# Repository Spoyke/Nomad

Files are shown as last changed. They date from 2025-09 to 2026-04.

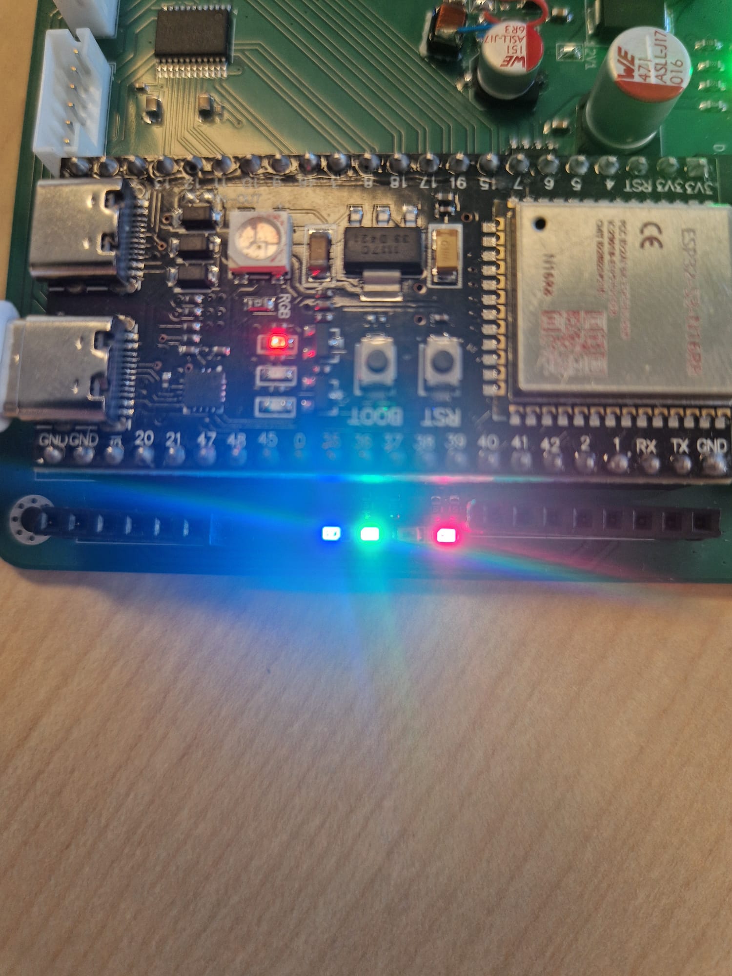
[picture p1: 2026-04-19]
Ressources/Fonctionnement de l'alimentation.jpeg

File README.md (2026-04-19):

 # **Son Spatial**
*Projet étudiant S7*

## Description du projet 

Ce projet a pour objectif de créer un système audio immersif mobile grâce à un réseau d’amplificateurs audio, capables de spatialiser le son. Le principe repose sur la distribution et le traitement différencié des signaux audio entre plusieurs amplificateurs, afin de recréer une expérience sonore 3D pour l’utilisateur. Le système s'adapte aux différentes pièces pour trouver 

### Principe de fonctionnement 

#### Microcontrôleur maître

- Reçoit le contenu audio à diffuser (ex : musique, film, jeu vidéo).
- Traite et décompose le signal audio pour chaque ampli, en fonction de leur position relative par rapport à l’utilisateur.
- Envoie les données audio adaptées à chaque ampli via un protocole de communication sans fil.

#### Amplificateurs audio

- Reçoivent les signaux audio spécifiques (ex du stéréo : piste gauche pour l’ampli gauche, piste droite pour l’ampli droit).
- Convertissent le signal numérique en signal analogique, l’amplifient, et le diffusent via des haut-parleurs.
- Synchronisent leur diffusion pour éviter les décalages.

### Exemple

Si un son provient de la gauche dans le contenu audio, l’utilisateur l’entendra principalement depuis l’ampli situé à sa gauche, avec une atténuation progressive vers la droite. Plus le nombre d’amplis est élevé (ex : 4 ou 6), plus la précision de la spatialisation est fine (avant/arrière, haut/bas).

## Architecture du projet

Le projet est divisé en deux parties principales, chacune avec des objectifs techniques spécifiques :

### Partie électronique

Cette partie correspond à la concéption et à la réalisation des amplificateurs audio.

#### Fonctions clés 

- Récupération du signal audio numérique
- Conversion numérique → analogique
- Amplification du signal

### Partie Informatique

Cette partie comporte la programmation des microcontroleurs (esp32), Rasberry PI, application mobile.
On vise à traiter le son et assurer une communication synchrone entre le microcontrôleur maître et les amplis.
- Le traitement de signal sera géré par la Rasberry Pi commandé via une interface mobile. 
- La communication entre l'application du telephone et la raspberry pi se fera via un serveur local WebSocket hebergé par la raspberry.
- La diffusion de la musique entre la raspberry pi et l'esp32 se fera à travers un serveur local Icecast hebergé par la raspberry.

### Partie mécanique

Cette partie vise à conceptionner plusieurs robots capables de se déplacer dans une pièce. 

#### Fonctions clés

- Extraction des pistes (gauche/droite, avant/arrière)
- Synchronisation des amplis

## Compte rendus de séance
### Séance 1 (16/09/2025)

*Julie, Simon, Gabriel* :

Réalisation en amont des schématique :
- Amplificateur audio pour diffuser du son via une application mobile
- Mécanique pour déplacer l'enceinte et éviter les obstacles
  
Mettre en commun les schématique afin de commander les composantes. 

*Axel, Aleksandar* : 

Etablir une communication entre les esp32 - Rasberry Pi - Téléphone
Transmission de son via une application mobile

### Séance 2 (23/09/2025)

"Julie, Simon, Gabriel" : 

- Fin de la réalisation et mise en commun des schémas de l'ampli audio et du robot.
- Ajout d'un capteur à ultrason au robot pour qu'il puisse détecter et anticiper les obstacles. Utilisation du HC-SR04.
- Choix final de l'esp32 et des empreintes des composants pour le PCB. 
- Début de la conception du PCB.

"Axel, Aleks" :

Design de l'interface de l'application
Début de communication entre un esp32 et la raspberry Pi

"Globale" :
- Recherche sur la façon dont les robots se localiser et comment l'implémenter : On utilisera l'intensité du signal émit par la raspberry pi à l'esp32 pour déterminer la distance entre les deux (plus l'intensité est faible, plus la distance est grande)

Planning prévisionnel :



### Séance 3 (30/09/2025)

Simon : commande des composants, continuer le PCB

Gabriel : Finition placement des composants pour le routage, routage des composants sauf pour l'esp32. 

Aleksandar : ecrire un code pour teste l'intensité d'un signal wifi avec un appareil. On remarque que des interférences viennent rapidement perturber le signal. Il faudrait amplifier le signal wifi ou trouver un autre solution pour le localisation des robots.

Axel : transmission d'un fichier audio avec la rasberry Pi sur l'esp32. Vérifier que le signal est bien lu sur l'esp32 avec un oscilloscope. Le son n'est pas assez puissant pour pouvoir l'écouter.Implémentation d'un système d'amplification du courant à la prochaine séance via le dac de l'esp32

Julie: conception mécanique du robot (modélisation Onshape)

### Séance 4 (07/10/2025)

Simon : Recherche sur les moyens de gérer les déplacement des amplis audio et reprérer les amplis dans l'espace. Utilisation de l'intensité du signal pour déterminer la distance entre la raspberry pi et les esp32. Et, les esp32 entre eux, en demendans au esp de transmettre un signal périodiquement pour permettre aux autres de déterminer la distance avec ce dernier. Dans le cas du projet de conférencier, le conférencier porte la raspberry pi et les esp32 se placent dans un rayon de 3m autour de ce dernier. Et, à une certaine distance (à déterminer) entre eux. Ainsi, chaque esp32 va essayer de rester à une distance de 3m du conférencier et suffisament espacé des autres esp32.

 Gabriel : Correction PCB

 Aleks : Correction du code pour l'intensité du signal wifi, manipulation entre deux ESP32 pour vérifier si l'un capte l'autre. On c'est procurer une antenne d'Arès que l'on a mis sur l'ESP32 ce qui a permis de corriger la perturbation des signaux et augmenter leur intensité à la réception de l'ESP32. Vérification de l'intensité du signal émis par un partage de connexion d'iphone en fonction de la distance

 Julie : Conception méca 

 Axel : Lecture du son reçue sur l'esp32 depuis la raspberry avec l'ampli audio LM386. Actuellement le son est de très mauvaise qualitée, mais reconnaisable, car il est diffusé par le DAC de l'esp32. Deux objectifs pour la prochaine séance : - essayer un autre DAC pour voir si la qualité est meilleurs et mise en place de l'application pour commencer le contrôle de la raspberry via le telephone.

### Séance 5 (21/10/2025)

Aleks : Implémentation d'un système de connexion dans le code qui scan les signaux Wi-Fi aux alentours, a présent, il est possible de se connecter a un réseau Wi-Fi tant que l'ESP32 capte le signal et tant que l'on connait le mot de passe du wifi (falcutatif)

Axel : Utilisation du LM386 mais peu fructueuse car il faut mettre un son de très faible amplitude ( ~= 50 mv max à cause du gain de 20 de l'ampli ), qui est presque impossible à avoir avec le DAC 8 bits de l'esp32. Test d'un ampli audio I2S pendant les vacances.

Simon : Début du travaille sur la synchronisation des ESP32 : La raspberry pi envoit des pacquets de données d'une taille à définir en fonction de la qualité du son et de la mémoire disponible sur l'esp32. Dans ce paquet, il y a 3 éléments : l'heure (nombre de microseconde depuis l'epoch) de la rasbperry pi lors de l'envoie du paquet, l'heure où le son doit être joué par l'esp32 et les données du son. De cette façon, la latence peut être estimer la latence qu'il y a eu en comparant l'heure de transmission et l'heure de l'esp32.  

Gabriel : finalisation pcb, creation gerbers, envoi en production

### Séance 6 (4/11/2025)

Aleks : Début de code sur la spatialisation des ESP32, le but sera d'estimer (pour l'instant de manière ni précise et plutôt naïve) la distance entre l'esp32 et la raspberry en fonction de l'intensité RSSI du signal wif.

Axel : Sur mon réseau wifi à domicile, tout est ok niveau transmission de l'audio et synchronisation. Arrivé à l'école, je me rends compte que le réseau de l'ecole bloque certains port d'écoute nécessaire à la partie informatique. Changement du partie du moyen de communication ( Mqtt -> serveur local WebSocket ).

Simon : Mise en place de multithreading pour permettre à l'esp32 de réaliser ses tâches (réception, émission, déplacement et envoit du son à l'ampli audio) en parallèle. Et, travaille sur la synchronisation : mise en place d'une queue pour stocker les paquets reçuent et pas encore traités car la réception des données est plus rapide que le traitement des paquets. Une fois le traitement du paquet terminé, le code créé un timer qui se déclanchera dans (heure du son à jouer - heure raspberry pi).  
 
Gabriel : verification avancement commande pcb, tests de fonctionnement capteur ultrasons, point sur la repartition des tâches avec le reste de l'equipe

Julie : Impression du premier prototypage du boîtier d'ampli audio. Tester l'ultrason et les moteurs pour la prochaine séance. Il faut aussi commander les moteurs, les esp32, les haut parleurs et les batteries pour la prochaine séance. 

### Séance 7 (19/11/2025)

Gabriel : Entretien sur fiche de compétances, recherche composants pour soudure pcb, reflexion à des solutions aux problèmes d'empruntes de composants 

Julie : Soudure des composants

Simon et Aleks : Travail sur la mesure de la distance entre les esp32 pour qu'ils puissent rester à une certaine distance les uns des autres. La première idée, d'utilisé le RSSI comme avec la raspberry pi ne fonctionne pas. La communication n'est pas direct, elle passe par la raspberry pi. Une solution serait d'utiliser ESP-Now pour communiquer directement entre les esp32 mais, cela signifierait de devori couper la communication wifi avec la raspberry pi quelque temps pour émettre un signal capté par les autres esp32.

Axel : Le son est synchronisé avec 3 esp32s, il faut maintenant le spatialiser.

### Séance 8 (25/11/2025)

Axel : Le son est maintenant stéréo. Prochaine étape : enregistrement et diffusion de la voix via un micro I2S

Simon Et Aleks : On a fait fonctionner le capteur à ultrason pour détecter les obstabcles sur la routes des amplis. Et, on a commencé travaillé sur le fonctionnement des moteurs.

Gabriel et Julie : Soudure des composants qui n'avaient pas les bonnes empruntes. Reflexion sur la prochaine version du pcb

### Séance 9 (02/12/2025)

Gabriel : Test du fonctionnement des composants et du fonctionnent général de la carte. applications solutions des problèmes de composants.

Simon : Test du PCB, la diode de schotky protégeant le circuit bloque la tension d'alimentation de 12V. Il y a des étincelles lorsqu'on branche le 12 d'une alim de labo à la carte. Le LDO ne fonctionne pas, il ne sort pas de 5V, le problème peut venir des soudures qui sont moins bonnes à cette endroit. Le LDO transformant le 5V en 3.3V fonctionne mais chauffe beaucoup, il n'y a peut être pas de problème, le drive moteur peut demander beaucoup de courant, ce qui fait chauffer le composant mais, il faudra réfléchir à un moyen de réduire la chaleur du composant dans le prochain PCB. Les Leds indiquant qu'il y a du 12V et du 1.8V ne fonctionnent pas (composant déféctueux ?). On a commencé à câbler la partie amplification avec l'esp32 mais il faut adapter le code pour pouvoir contrôler le composant.  

Axel : Test du micro I2S pas concluant => prochaine solutions : utilisation du micro du telephone

Aleks : Début de recherche et de programmation pour le mouvement des moteurs

Point sur la solution technique du déplacement et la répartition des tâches: 
Capture d’écran 2025-11-04 à 19 11 56

### Séance 10 (09/12/2025)

Axel : Test du micro I2S enfin concluant, possibilité de le lire sur le pc, il faut maintenant l'envoyer sur le serveur icecast

Gabriel : Répartition des composants sur 3 cartes differentes avec Simon, création projets kicad pour les prochains pcbs, schéma elec carte commande, recherche empruntes et symboles pour composants.

Simon : Travail sur le schéma du PCB de la partie audio, vérification des calculs, du choix et du placments des composants. Tout est bon, le plus gros changement par rapport à la version antérieur est le fait d'utiliser le PWR_MODE1 de l'ampli qui lorsque l'amplification est faible, l'ampli tire son alimentation depuis une source externe plus faible (qui vient du buck) pour moins consommer. Cependant, il faut vérifier que le courant fournit par le buck peut supporter cet ajout et s'il peut le faire sans problème (chauffe etc...). Réflexion sur le déplacment des robots, j'ai trouvé une façon qui même si elle est peu précise devrait suffire pour l'application, sans ajouter de nouveau composant : le robot cherche à se mettre à une certaine distance de la raspberry pi avec le calcul de distance basé sur le RSSI du signal reçu. Et, avec les deux capteurs à ultrasons, le robot cherche à se mettre à une certaine distance des autres robots (les capteurs à ultrasons ayant une porté de 4m). On peut donc faire en sorte que les robots soit à bonne distance de la raspberry pi et les uns des autres pour fournir un son sur une large zone, ce qui est le but du conférencier.  

Aleks : Continuation de la programmation du mouvement des moteurs, mesure et estimation de la distance entre l'esp32 et la raspberry PI avec le RSSI

### Séance 11 (16/12/2025)

Aleks : Estimation de la distance entre esp32 et Raspberry PI faite, code du MotorDriver (TB6612FNG) terminé (en théorie). Objectif de la prochaine séance : codé un encodeur et les moteurs en eux-même.

Simon : Réalisation du PCB de la partie audio qui est presque terminé, mais il faudra attendre la prochaine séance pour envoyer la commande et être sûr qu'il puisse être utilisé avec les autres modules du robot (connecteurs aux bons endroits et dont la connexion entre les autres PCB n'est pas géné par les composants. J'ai aussi fait un bilan du courant consommé par le robot et je me suis rendu compte que le buck ne pourrait pas fournir un courant suffisant lorsque tous les composants fonctionnent au maximum (ce qui devrait être assez rare). On a donc décidé avec Gabriel d'utiliser deux buck (soit le buck actuelle qui sera utilisé jusqu'à ce qu'on le remplace par un autre buck plus puissant à un endroit prévu. Soit on utilise deux fois le même buck mais un des deux serait décdié au fonctionnement de l'ampli.).  

### Séance 12 (13/01/2026)

Tout le monde : Mise en accord sur le planning prévisionnel

Aleks : début de la partie cartographie en expérimentant des capteurs dont le fonctionnement est similaire à un Lidar à l'aide d'une librairie Arduino, pour le moment pas de résultat concret à cause de certaine erreur lié a la partie programmation et au branchement des PINs

Simon : Mise au propre du planning prévisionnel sur Google Agenda (lien tout en bas). Fin du routage de la partie audio.

Gabriel : Finitions schéma elec carte CMD, début routage carte CMD, verification routage partie audio

Axel : Début d'utilisation et de diffusion du son du micro sur un esp32.

Julie : Revoir les capteurs pour mesurer la distance de capture objet
Modifier et finir la schématique pour l'implémenter avec le PCB d'alimentation. Voir avec Gabriel pour le routage. 

### Séance 13 (20/01/2026)

Simon : Fin du routage du PCB de la partie audio. 

Gabriel : Routage PCB Cmd, recherche composants.

Axel : Complication au niveau de la diffusion de la voix, un problème surement lié au format de données envoyée

Julie: Etude des capteurs

Aleks : Fonctionnement du détecteur infrarouge VL53L0X, estimation correcte jusqu'a une distance d'environ 1m.

### Séance 14 (27/01/2026)

Gabriel : fin du routage pcb cmd

Simon : Fin du routage de la partie audio (adaptation du pcb de la partie audio au pcb de la partie commande). J'ai aussi essayé de faire fonctionner le premier PCB (en enlevant le buck qui ne fonctionnait pas) pour faire des tests avec l'ampli audio. Notamment communiquer avec lui et le configurer pour qu'il soit conforme à ce qu'on à besoin (puissance maximale, moyen de communication (I2S), type d'alimentation...). 

Axel : La transmission du micro depuis le telephone vers l'esp32 est fonctionnelle

Julie : Branchement d'un moteur avec le module driver pour faire tourner le moteur. 

Aleks: Finalisation "théorique" du programme concernant la cartographie, mais il faut tester ce dernier.

### Séance 15 (03/02/2026)

Julie : Deuxième prototype de boitier imprimé 3D. A tester avec deux moteurs et mesurer le courant nominal pour un fonctionnement normal. Voir le support le poids avec l'assemblage. 

Simon et Aleks : On a essayé de faire fonctionner l'ampli de l'ancien PCB. Le PCB a différents problème comme le manque de résistance de pull-up sur les pins de l'I2C. Ce qui a compliquer la tâche. Au final, on arrive à envoyer la configuration à l'ampli mais on n'arrive pas à demander des données de l'ampli. 

Gabriel : finalisation du routage cmd + création d'un schéma de cablage pour le test des moteurs. Cablage de ces moteurs et début de création d'un programme de test.

### Séance 16 (10/02/2026)

Simon et Aleks : On a compris pourquoi la communication avec le TAS2780 ne fonctionnait pas : l'ampli utilise du 1.8V pour ses pins numériques alors que l'esp32 utilise du 3.3V. Et en recevant du 3.3V, l'ampli se met en sécurité. Ce qui empêche la communication. 

Gabriel : Continuation du programme de test moteurs, réussite, les moteurs tournent. Tests avec Julie du couple des moteurs alimentés directement sans controleur sur le prototype du robot, et tests de couple sur les moteurs controlés depuis l'esp 32.

Axel : Avancement dans la voix, plus beaucoup de micro coupures dues au rechargement du buffer

Julie : Reprise du PCB Commande, notamment il faut changer les empreintes suite à l'arrivée de la deuxième version du PCB contenant des mauvaise empreintes. 

### Séance 17 (17/02/2026)

Simon et Gabriel : Soudure de la carte 

Julie : Continuation du PCB commande. La commander pour la recevoir à la rentrée. 

### Séance 18 (10/03/2026)

Simon : Soudure des derniers composants sur le pcb audio (connecteur). Et test de la carte : -> la communication I2C fonctionne mais pour l'instant il n'y a pas de son en sortie de l'ampli. 

Gabriel : Création montage pour test encodeurs et début création code test encodeurs.

Julie : Continuation du PCB commande

### Séance 19 (17/03/2026)

Gabriel : Test encodeurs, création morceaux de code pour detecter le sens de rotation du moteur aunsi que valeur absolue pour vérifier vitesse. Finitions pcb fait par Julie.

Julie : Verification PCB et commande du PCB.

Simon : Travail sur le PCB de la partie audio -> L'I2C semble fonctionner

### Séance 20 (24/03/2026)

Gabriel : Finitions code encodeurs, test avec driver moteurs.

Julie : Soudure sur le PCB commandé la semaine précédente. Vérification des erreurs corrigés (empreintes, tailles pistes pour laisser passer le courant). Dimension du boitiers à refaire pour optimiser l'emplacement du PCB, moteurs et haut parleur. 

Simon : Travail sur le PCB de la partie audio, l'I2C semble fonctionner mais je ne sais pas pourquoi. Quand je met l'adresse du composant, la communication ne passe pas mais quand je met une autre adresse (0x38) la communication semble fonctionner sauf quand j'essaye de lire les valeurs d'un registre qui crée des problème. De même quand j'essai de lancer l'ampli, la communication ne fonctionne pas mais quand je n'essai pas de lancer l'ampli et que j'écrit seulement dans les registres de configuration, la communication semble fonctionner. Le problème vient peut être du pin d'adressage du composant mais après l'avoir ressoudé avec Patricia, je n'ai pas vu de différence dans les résultats. L'erreur dans la lecture vient peut-être du code qui ne terminait jamais la transmission mais encore, sans terminer la communication, j'avais des valeurs quand je lisais plusieurs registres différents et dans la même communication.

Axel : Son du micro enfin fonctionnel sur l'ESP32, il faut maintenant harmoniser le code de la gestion de l'audio

### Séance extra 21 (07/04/2026)

Teste de l'alimentation du PCB : 3V3, 5V, 12V marchent très bien. En revanche, le PCB audio fait court-circuiter une piste, ce qui entraine le surchauffe de la bobine. L'esp 32 est fonctionne bien sur le PCB et les connecteurs sont bien reliés aux capteurs. 

## Ressources

### Lien utiles

Diapo : https://docs.google.com/presentation/d/1eaNsvsmn-reTe-8X8-2-HZ8j_HwDIsKxUu0F8LIjo8Q/edit?usp=sharing \
Rapport : https://docs.google.com/document/d/1yTh4eJWGzI2o9GAGtWadODZ8SpGP1pLww7qxfcwqxjY/edit?usp=sharing \
https://www.notion.so/Partie-informatique-266923f17b6e80f486edd3fc771489f0 \
Infos MPU6050 https://docs.google.com/document/d/1O3AgjvM2_tZX7ABNkbS3lNtyRqeFLNvJ6qVK9URJxNs/edit?usp=sharing

### RSE

### Planning prévisionnel du 2nd semestre

https://calendar.google.com/calendar/ical/73473c3522efe55f20496e4b81c19aa0aaffa0a2a7005d1d658da9e635591a50%40group.calendar.google.com/public/basic.ics

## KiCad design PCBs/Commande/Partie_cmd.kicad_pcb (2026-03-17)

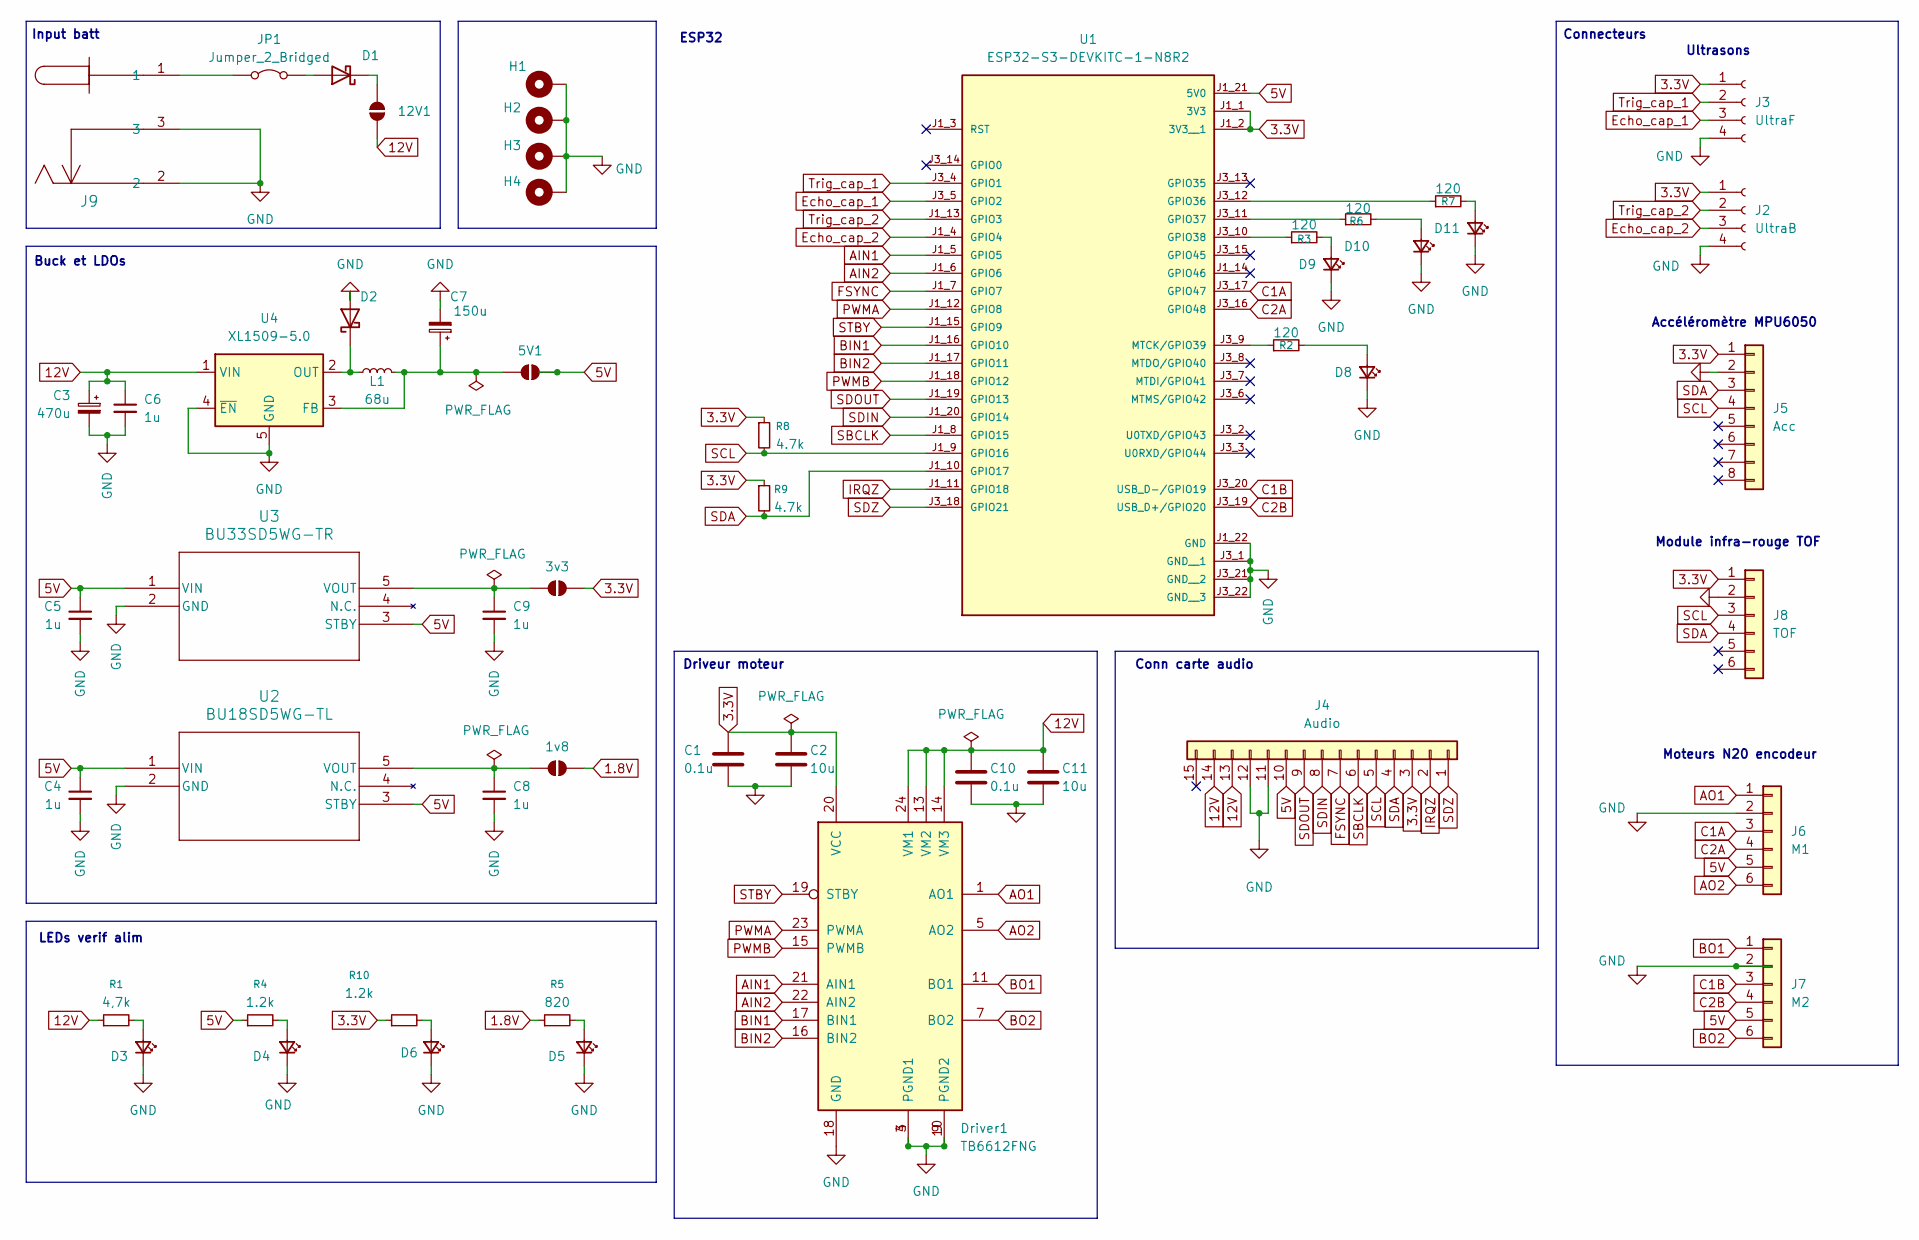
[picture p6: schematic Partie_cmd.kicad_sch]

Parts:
1v8, 3v3, 5V1, 12V1: SolderJumper_2_Open; SolderJumper-2_P1.3mm_Open_TrianglePad1.0x1.5mm
C1, C10: 0.1u; C_0402_1005Metric
C2, C11: 10u; C_0805_2012Metric
C3: 470u; CP_Elec_8x10.5
C4, C5, C6, C8, C9: 1u; C_0603_1608Metric_Pad1.08x0.95mm_HandSolder
C7: 150u; CP_Elec_6.3x7.7
D1, D2: MBRS320; D_SMC
D3, D4, D5, D6, D8, D9, D10, D11: LED_Small; LED_0603_1608Metric_Pad1.05x0.95mm_HandSolder
Driver1: TB6612FNG; SSOP-24_5.3x8.2mm_P0.65mm
H1, H2, H3, H4: MountingHole_Pad; MountingHole_2.5mm_Pad_Via
J2: UltraB; PinHeader_1x04_P2.54mm_Vertical
J3: UltraF; PinHeader_1x04_P2.54mm_Vertical
J4: Audio; PinSocket_1x15_P2.00mm_Vertical
J5: Acc; PinHeader_1x08_P2.54mm_Vertical
J6: M1; JST_PH_B6B-PH-K_1x06_P2.00mm_Vertical
J7: M2; JST_PH_B6B-PH-K_1x06_P2.00mm_Vertical
J8: TOF; PinHeader_1x06_P2.54mm_Vertical
J9: 694106105102; CONN3_06105102_WRE
JP1: Jumper_2_Bridged; TestPoint_2Pads_Pitch2.54mm_Drill0.8mm
L1: 68u; L_0805_2012Metric_Pad1.05x1.20mm_HandSolder
R1: 4,7k; R_0603_1608Metric_Pad0.98x0.95mm_HandSolder
R2, R3, R6, R7: 120; R_0603_1608Metric_Pad0.98x0.95mm_HandSolder
R4, R10: 1.2k; R_0603_1608Metric_Pad0.98x0.95mm_HandSolder
R5: 820; R_0603_1608Metric_Pad0.98x0.95mm_HandSolder
R8, R9: 4.7k; R_0603_1608Metric_Pad0.98x0.95mm_HandSolder
U1: ESP32-S3-DEVKITC-1-N8R2; XCVR_ESP32-S3-DEVKITC-1-N8R2; PARTREV V1
U2: BU18SD5WG-TL; SSOP5_ROM-L
U3: BU33SD5WG-TR; SSOP5_ROM-L
U4: XL1509-5.0; SOIC-8_3.9x4.9mm_P1.27mm

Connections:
1.8V: 1v8.2 (B), R5.1
3.3V: 3v3.2 (B), C1.1, C2.1, Driver1.20 (VCC), J2.1, J3.1, J4.3, J5.1, J8.1, R8.1, R9.1, R10.1, U1.J1_1 (3V3), U1.J1_2 (3V3__1)
5V: 5V1.2 (B), C4.1, C5.1, J4.10, J6.5, J7.5, R4.1, U1.J1_21 (5V0), U2.1 (VIN), U2.3 (STBY), U3.1 (VIN), U3.3 (STBY)
12V: 12V1.2 (B), C3.1, C6.1, C10.1, C11.1, Driver1.13 (VM2), Driver1.14 (VM3), Driver1.24 (VM1), J4.13, J4.14, R1.1, U4.1 (VIN)
AIN1: Driver1.21 (AIN1), U1.J1_5 (GPIO5)
AIN2: Driver1.22 (AIN2), U1.J1_6 (GPIO6)
AO1: Driver1.1 (AO1), Driver1.2 (AO1), J6.1
AO2: Driver1.5 (AO2), Driver1.6 (AO2), J6.6
BIN1: Driver1.17 (BIN1), U1.J1_16 (GPIO10)
BIN2: Driver1.16 (BIN2), U1.J1_17 (GPIO11)
BO1: Driver1.11 (BO1), Driver1.12 (BO1), J7.1
BO2: Driver1.7 (BO2), Driver1.8 (BO2), J7.6
C1A: J6.3, U1.J3_17 (GPIO47)
C1B: J7.3, U1.J3_20 (USB_D-/GPIO19)
C2A: J6.4, U1.J3_16 (GPIO48)
C2B: J7.4, U1.J3_19 (USB_D+/GPIO20)
Echo_cap_1: J3.3, U1.J3_5 (GPIO2)
Echo_cap_2: J2.3, U1.J1_4 (GPIO4)
FSYNC: J4.7, U1.J1_7 (GPIO7)
GND: C1.2, C2.2, C3.2, C4.2, C5.2, C6.2, C7.2, C8.2, C9.2, C10.2, C11.2, D2.2 (A), D3.1 (K), D4.1 (K), D5.1 (K), D6.1 (K), D8.1 (K), D9.1 (K), D10.1 (K), D11.1 (K), Driver1.3 (PGND1), Driver1.4 (PGND1), Driver1.9 (PGND2), Driver1.10 (PGND2), Driver1.18 (GND), H1.1, H2.1, H3.1, H4.1, J2.4, J3.4, J4.11, J4.12, J5.2, J6.2, J7.2, J8.2, J9.2, J9.3, U1.J1_22 (GND), U1.J3_1 (GND__1), U1.J3_21 (GND__2), U1.J3_22 (GND__3), U2.2 (GND), U3.2 (GND), U4.4 (~EN), U4.5 (GND), U4.6 (GND), U4.7 (GND), U4.8 (GND)
IRQZ: J4.2, U1.J1_11 (GPIO18)
unnamed: 1v8.1 (A), C8.1, U2.5 (VOUT)
unnamed: 3v3.1 (A), C9.1, U3.5 (VOUT)
unnamed: 5V1.1 (A), C7.1, L1.2, U4.3 (FB)
unnamed: 12V1.1 (A), D1.1 (K)
unnamed: D1.2 (A), JP1.2 (B)
unnamed: D2.1 (K), L1.1, U4.2 (OUT)
unnamed: D3.2 (A), R1.2
unnamed: D4.2 (A), R4.2
unnamed: D5.2 (A), R5.2
unnamed: D6.2 (A), R10.2
unnamed: D8.2 (A), R2.2
unnamed: D9.2 (A), R3.2
unnamed: D10.2 (A), R6.2
unnamed: D11.2 (A), R7.2
unnamed: J9.1, JP1.1 (A)
unnamed: R7.1, U1.J3_12 (GPIO36)
unnamed: R6.1, U1.J3_11 (GPIO37)
unnamed: R3.1, U1.J3_10 (GPIO38)
unnamed: R2.1, U1.J3_9 (MTCK/GPIO39)
PWMA: Driver1.23 (PWMA), U1.J1_12 (GPIO8)
PWMB: Driver1.15 (PWMB), U1.J1_18 (GPIO12)
SBCLK: J4.6, U1.J1_8 (GPIO15)
SCL: J4.5, J5.4, J8.3, R8.2, U1.J1_9 (GPIO16)
SDA: J4.4, J5.3, J8.4, R9.2, U1.J1_10 (GPIO17)
SDIN: J4.8, U1.J1_20 (GPIO14)
SDOUT: J4.9, U1.J1_19 (GPIO13)
SDZ: J4.1, U1.J3_18 (GPIO21)
STBY: Driver1.19 (STBY), U1.J1_15 (GPIO9)
Trig_cap_1: J3.2, U1.J3_4 (GPIO1)
Trig_cap_2: J2.2, U1.J1_13 (GPIO3)

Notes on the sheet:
Buck et LDOs
LEDs verif alim
Input batt
Accéléromètre MPU6050
Moteurs N20 encodeur
Module infra-rouge TOF
Ultrasons
ESP32
Connecteurs
Conn carte audio
Driveur moteur

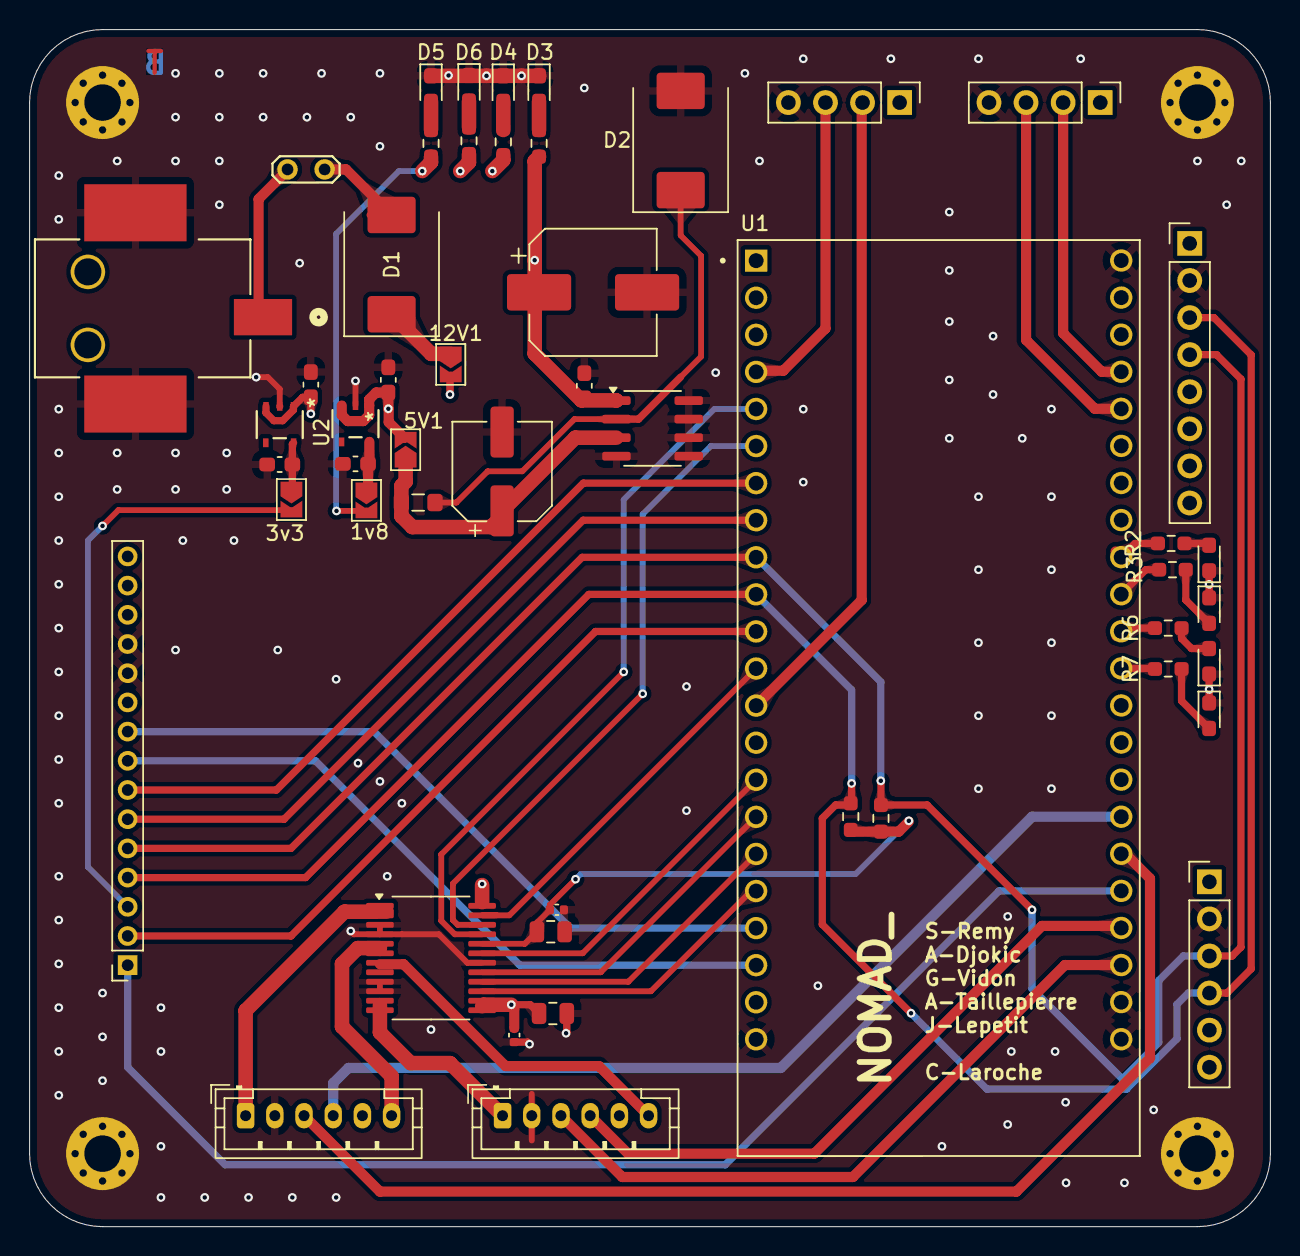
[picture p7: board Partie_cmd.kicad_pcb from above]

Board: 4 copper layers, 85.0 x 82.0 mm, 54 parts (0 on the bottom side), 51 nets.

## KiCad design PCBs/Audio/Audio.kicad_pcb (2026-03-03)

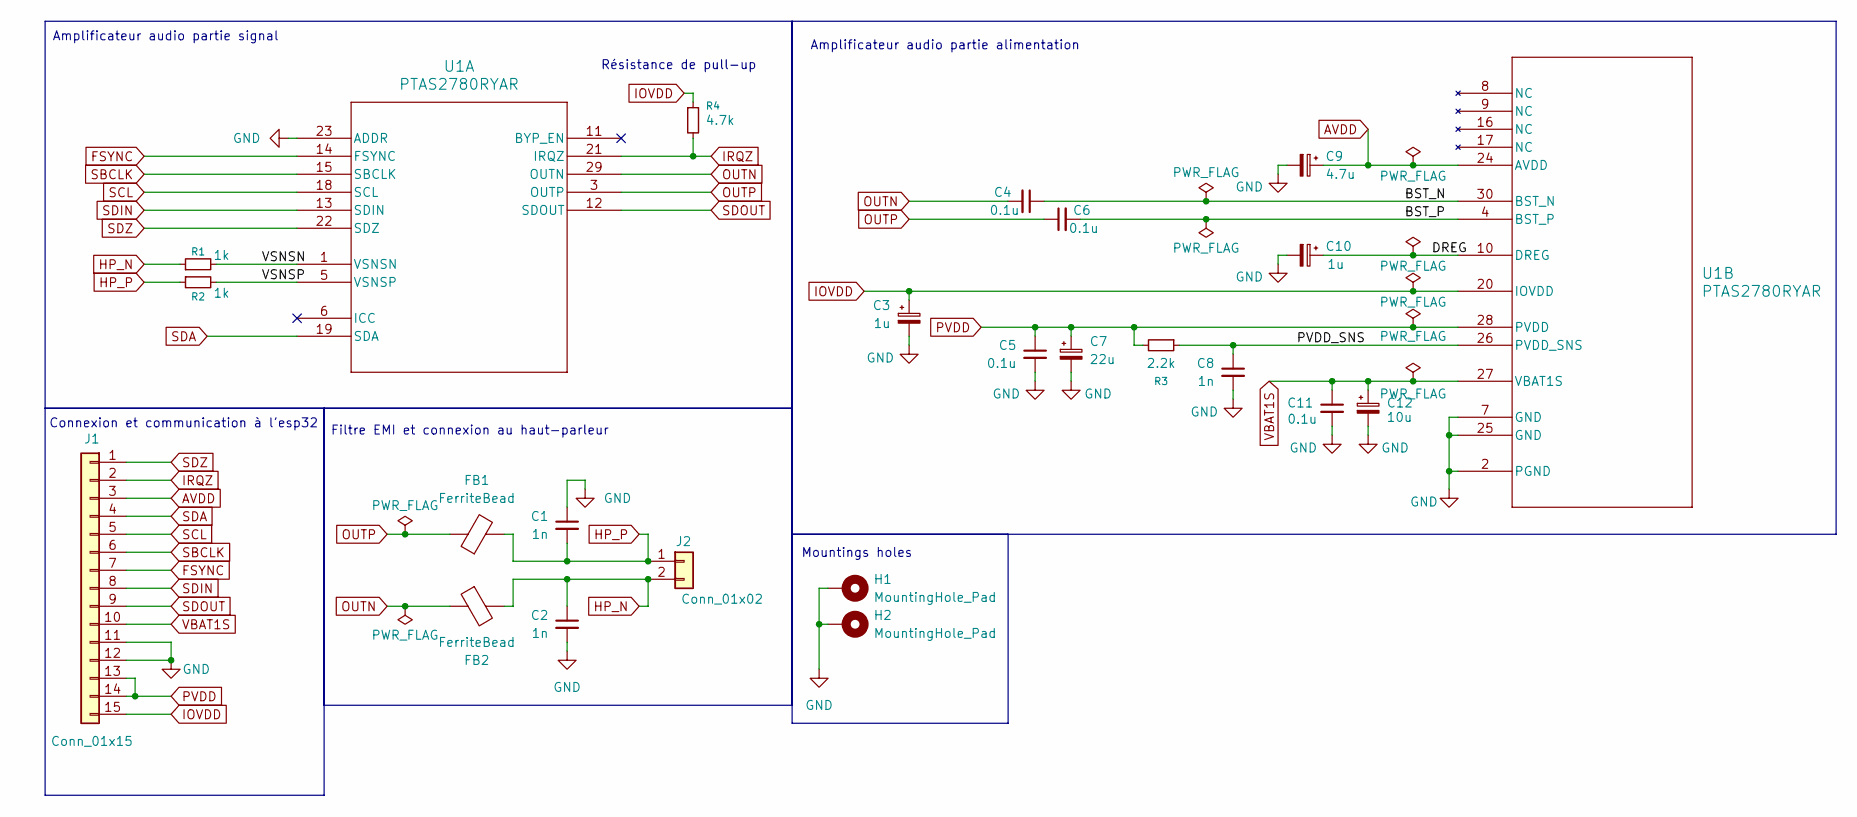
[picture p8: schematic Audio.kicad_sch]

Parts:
C1, C2, C8: 1n; C_0603_1608Metric_Pad1.08x0.95mm_HandSolder
C3, C10: 1u; C_0603_1608Metric_Pad1.08x0.95mm_HandSolder
C4, C6, C11: 0.1u; C_0603_1608Metric_Pad1.08x0.95mm_HandSolder
C5: 0.1u; C_0805_2012Metric_Pad1.18x1.45mm_HandSolder
C7: 22u; C_1210_3225Metric_Pad1.33x2.70mm_HandSolder
C9: 4.7u; C_0603_1608Metric_Pad1.08x0.95mm_HandSolder
C12: 10u; C_0805_2012Metric_Pad1.18x1.45mm_HandSolder
FB1, FB2: FerriteBead; C_1206_3216Metric_Pad1.33x1.80mm_HandSolder
H1, H2: MountingHole_Pad; MountingHole_2.2mm_M2_DIN965_Pad
J1: Conn_01x15; PinHeader_1x15_P2.00mm_Vertical
J2: Conn_01x02; PinHeader_1x02_P2.00mm_Vertical
R1, R2: 1k; R_0603_1608Metric_Pad0.98x0.95mm_HandSolder
R3: 2.2k; R_0603_1608Metric_Pad0.98x0.95mm_HandSolder
R4: 4.7k; R_0603_1608Metric_Pad0.98x0.95mm_HandSolder
U1: PTAS2780RYAR; VQFN-HR_RYA_TEX

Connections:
/BST_N: C4.1, U1.30 (BST_N)
/BST_P: C6.2, U1.4 (BST_P)
/DREG: C10.1, U1.10 (DREG)
/PVDD_SNS: C8.1, R3.1, U1.26 (PVDD_SNS)
/VSNSN: R1.2, U1.1 (VSNSN)
/VSNSP: R2.2, U1.5 (VSNSP)
AVDD: C9.1, J1.3, U1.24 (AVDD)
FSYNC: J1.7, U1.14 (FSYNC)
GND: C1.1, C2.2, C3.2, C5.2, C7.2, C8.2, C9.2, C10.2, C11.2, C12.2, H1.1, H2.1, J1.11, J1.12, U1.2 (PGND), U1.7 (GND), U1.23 (ADDR), U1.25 (GND)
HP_N: C2.1, FB2.2, J2.2, R1.1
HP_P: C1.2, FB1.2, J2.1, R2.1
IOVDD: C3.1, J1.15, R4.1, U1.20 (IOVDD)
IRQZ: J1.2, R4.2, U1.21 (IRQZ)
OUTN: C4.2, FB2.1, U1.29 (OUTN)
OUTP: C6.1, FB1.1, U1.3 (OUTP)
PVDD: C5.1, C7.1, J1.13, J1.14, R3.2, U1.28 (PVDD)
SBCLK: J1.6, U1.15 (SBCLK)
SCL: J1.5, U1.18 (SCL)
SDA: J1.4, U1.19 (SDA)
SDIN: J1.8, U1.13 (SDIN)
SDOUT: J1.9, U1.12 (SDOUT)
SDZ: J1.1, U1.22 (SDZ)
VBAT1S: C11.1, C12.1, J1.10, U1.27 (VBAT1S)

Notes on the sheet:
Amplificateur audio partie alimentation
Connexion et communication à l'esp32
Résistance de pull-up
Mountings holes
Amplificateur audio partie signal
Filtre EMI et connexion au haut-parleur

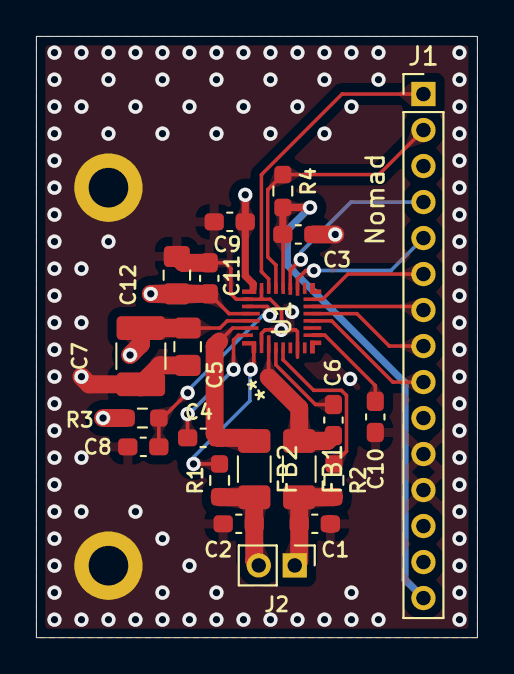
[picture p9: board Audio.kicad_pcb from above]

Board: 4 copper layers, 24.5 x 33.4 mm, 23 parts (0 on the bottom side), 23 nets.

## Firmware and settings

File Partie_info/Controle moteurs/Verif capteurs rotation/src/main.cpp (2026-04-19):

#include <Arduino.h>
#include <Wire.h>
#include <esp32-hal-ledc.h>

// put function declarations here:
int AI1 = 5; // GPIO pin for AI1 (pin 5)
int AI2 = 6; // GPIO pin for AI2 (pin 6)
int pwmPin = 8; // GPIO pin for PWM (pin 12)
int pwmChannel = 0;  // LEDC channel (0-15)
int pwmFreq = 20000; // Frequency in Hz
int pwmResolution = 8; // Resolution in bits (0-255 for 8 bit res)
int pinC1 = 47; // GPIO pin for encoder channel 1
int pinC2 = 48; // GPIO pin for encoder channel 2
int prevState = 0;
int encoderPosition = 0; // Position of the encoder

int ledpins[] = {39, 38, 37, 36}; // GPIO pins for LEDs (pins 39, 38, 37, 36)

// Quadrature transition table: index = (prevState << 2) | state
// +1 = clockwise, -1 = counterclockwise, 0 = no move/invalid
const int8_t transitionTable[16] = {
  0,  -1,  1,   0,
  1,   0,   0,  -1,
  -1,  0,   0,   1,
  0,   1,  -1,   0
};

void setup() {
  Serial.begin(115200);
  pinMode(AI1, OUTPUT);
  pinMode(AI2, OUTPUT);
  pinMode(pinC1, INPUT_PULLUP);
  pinMode(pinC2, INPUT_PULLUP);

  pinMode(ledpins[0], OUTPUT);
  pinMode(ledpins[1], OUTPUT);
  pinMode(ledpins[2], OUTPUT);
  pinMode(ledpins[3], OUTPUT);
  digitalWrite(ledpins[0], HIGH);
  digitalWrite(ledpins[1], HIGH);
  digitalWrite(ledpins[2], HIGH);
  digitalWrite(ledpins[3], HIGH);

  ledcSetup(pwmChannel, pwmFreq, pwmResolution); // channel, freq, resolution
  ledcAttachPin(pwmPin, pwmChannel); // attach GPIO pin to LEDC channel

  

  digitalWrite(AI1, LOW);
  digitalWrite(AI2, HIGH); // Setting to spin in one direction

  prevState = (digitalRead(pinC1) << 1) | digitalRead(pinC2);
  Serial.println("Setup finished.");
}

void loop() {
  int c1 = digitalRead(pinC1);
  int c2 = digitalRead(pinC2);
  int state = (c1 << 1) | c2;

  ledcWrite(pwmChannel, 100);

  if (state != prevState) {
    int index = (prevState << 2) | state;
    int8_t delta = transitionTable[index];
    if (delta == 1) {
      encoderPosition++;
      //Serial.println("Encoder turned clockwise");
    } else if (delta == -1) {
      encoderPosition--;
      //Serial.println("Encoder turned counterclockwise");
    }
    prevState = state;
  }

  static unsigned long lastPrint = 0;
  if (millis() - lastPrint >= 200) {
    lastPrint = millis();
    Serial.printf("Encoder pos: %d, AI1: %d, AI2: %d\n", encoderPosition, digitalRead(AI1), digitalRead(AI2));
    Serial.printf("PWM duty: %d\n", ledcRead(pwmChannel));
  }

}

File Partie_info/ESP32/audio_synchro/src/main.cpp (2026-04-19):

#include <Arduino.h>
#include <WiFi.h>
#include <WiFiUdp.h>
#include <WebSocketsClient.h>
#include "MyWebSocket.h"
#include "AudioLogger.h"
#include "SnapClient.h"
#include <WebSocketsClient.h>
#include <Audio.h>

// --- VARIABLES DE SYNCHRO ---
uint32_t targetEpochMillis = 0;
bool hasTargetTime = false;
const char url[] = "http://10.42.0.1:8000/streamleft";
// Pins pour gérer l'I2S
int _bck = 17, _ws = 18, _data = 16;    
int volume = 3;
const char *ssid = "MonHotspot";
const char *password = "axel1234";
bool isIcecast = true;
I2SStream out; 
WiFiClient wifi;
CopyDecoder decoder; 
SnapClient client(wifi, out, decoder);
Audio audio;
bool i2sInitialized = false; // Flag pour savoir si on doit désinstaller
void releaseI2S() {
    Serial.println("Libération des ressources I2S...");
    
    // On n'arrête que si cela a déjà été lancé
    if (i2sInitialized) {
        // On arrête les flux logiciels d'abord
        audio.stopSong(); 
        out.end();
        
        // On désinstalle le driver hardware proprement
        i2s_driver_uninstall((i2s_port_t)0); 
        i2sInitialized = false;
        delay(100); // Petite pause pour laisser le hardware respirer
    }
}

void init_I2S_SnapCast(){ 
  releaseI2S();
  
  auto cfg = out.defaultConfig(TX_MODE);
  cfg.pin_bck = _bck;
  cfg.pin_ws = _ws;
  cfg.pin_data = _data;
  cfg.sample_rate = 44100;
  cfg.channels = 2;
  cfg.bits_per_sample = 16;
  client.setVolumeFactor(.25);
  
  out.begin(cfg);
  client.begin();
  
  i2sInitialized = true; // On marque comme initialisé
  isIcecast = false;
}

void init_I2S_Icecast(){
  releaseI2S();
  
  audio.setPinout(_bck, _ws, _data);
  audio.setVolume(volume);
  
  i2sInitialized = true; // On marque comme initialisé
  isIcecast = true;
}

void webSocketEvent(WStype_t type, uint8_t * payload, size_t length) {
    switch(type) {
        case WStype_TEXT: {
            char target[8], command[16], content[32];
            if (!extractField((char*)payload, "target", target, sizeof(target))) return;            
            if (strcmp(target, "esp32") == 0) {
                extractField((char*)payload, "command", command, sizeof(command));
                extractField((char*)payload, "content", content, sizeof(content));

                if (strcmp(command, "Sync") == 0) {   
                  //  init_I2S_Icecast();                 
                    init_I2S_Icecast();
                    targetEpochMillis = atoll(content);
                    hasTargetTime = true;
                } else if (strcmp(command, "Stop") == 0) {
                    if(audio.isRunning()){
                        audio.stopSong();
                        Serial.println("Lecture arrêtée.");
                    }
                    init_I2S_SnapCast();
                } else if (strcmp(command, "Volume") == 0) {
                    volume = atoi(content);
                    audio.setVolume(volume);
                }
            }
        } break;
        case WStype_DISCONNECTED: Serial.println("WS Déconnecté"); break;
        case WStype_CONNECTED: Serial.println("WS Connecté"); break;
        default: break;
    }
}

void setup() {
  Serial.begin(115200);
  WiFi.begin(ssid, password);
  while (WiFi.status() != WL_CONNECTED) {
    delay(500);
    Serial.print(".");
  }
  Serial.println("Connecté !");
  
  WS_init(webSocketEvent); 
}

void loop() {
  WS_loop();  
  if(isIcecast){
    audio.loop();
    if (hasTargetTime) {
      audio.setVolume(volume);
      audio.connecttohost(url);
      hasTargetTime = false;
    }
  }
  else{
    client.doLoop();
  }

  
}

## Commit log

2025-09-23 Nouvelle version schéma kicad
    changement de nom + nouveau schéma elec
    [Nomad.kicad_pcb, Nomad.kicad_sch]
2025-09-23 retouches schema elec
    [Nomad.kicad_sch]
2025-09-25 Merged branches
    [ESP32-DEVKITC-32UE.step, Nomad.kicad_pcb, Nomad.kicad_sch]
2025-09-26 small fixes
    resolved erc errors
    [Nomad.kicad_sch]
2025-09-30 routage pcb
    finitions placement composants + routage
    [Nomad.kicad_pcb, Nomad.kicad_sch]
2025-09-30 Fin routage
    Fin routage sauf pour esp
    [Nomad.kicad_pcb]
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2025-10-06 Finished routing and silkscreen placement
    todo Gerber
    [Nomad.kicad_pcb, Nomad.kicad_sch]
2025-10-07 schéma ancien routage final ver
    [Nomad.kicad_pcb]
2025-10-07 encore plus de routage :(
    Todo, rapprocher au max capa de découplage
    grossir pistes alim au max
    [Nomad.kicad_pcb]
2025-10-08 Fin routage
    pls j'espère que c'est fini
    [Nomad.kicad_pcb]
2025-10-08 fin routage
    ok normalement là c'est bon
    [Nomad.kicad_pcb]
2025-10-14 Réorganisation des dossiers
    Séparation de la partie info et la partie élec
    [ESP32-DEVKITC-32UE.step, Nomad.kicad_pcb, Nomad.kicad_sch]
2025-10-15 Elargissement des pistes d'alim en interne
    [Nomad.kicad_pcb]
2025-10-15 Changements demandés par prof
    [Nomad.kicad_pcb, Nomad.kicad_sch]
2025-10-15 see prev commit message
    [Nomad.kicad_pcb]
2025-10-21 PCB Finalise
    finalisation pcb, création fichiers gerber
    [Nomad-B_Cu.gbr, Nomad-B_Mask.gbr, Nomad-B_Paste.gbr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]
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2025-11-05 Mettre à jour les progrès de l'équipe dans le README
    Ajout des mises à jour des membres de l'équipe concernant la synchronisation des ESP32, le multithreading et d'autres tâches en cours.
2025-11-22 Update README with ESP32 project details
    Added details about distance measurement and sound synchronization with ESP32 devices.
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2025-12-02 Reroganisation fichier + création docs pour v2 des pcb
    voir titre
    [Carte_puiss_Nomad.kicad_pcb, Carte_puiss_Nomad.kicad_sch, Carte_sig_Nomad.kicad_pcb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]
2025-12-02 Document Simon's PCB testing findings
    Added details about Simon's testing of the PCB and issues encountered.
2025-12-09 Remove Nomad PCB and schematic files
    Deleted all KiCad project, schematic, PCB, and backup files for both 'Carte puissance' and 'Carte signal' boards in PCB_v2, as well as a lock file in PCB_v1. This cleans up obsolete or unused design 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
    [Carte_puiss_Nomad.kicad_pcb, Carte_puiss_Nomad.kicad_sch, Carte_sig_Nomad.kicad_pcb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]
2025-12-09 creation fichiers
    [Nomad.kicad_pcb, Partie_audio.kicad_pcb, Partie_audio.kicad_sch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]
2025-12-09 Création du pcb cmd
    [Partie_cmd.kicad_sch]
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2025-12-16 pcb commande empruntes + debut routage
    [Partie_cmd.kicad_pcb]
2025-12-17 see previous commit
    [Partie_cmd.kicad_sch]
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2026-01-13 PCB méca
    Fusionner la partie méca avec alim
    [Partie_moteurs.kicad_sch, Partie_mécanique .kicad_pcb, Partie_mécanique .kicad_sch]
2026-01-13 Add new KiCad PCB and schematic files for Partie_cmd
    Added new footprints, backup files, and autosave files for the Partie_cmd project in PCBs_v2, including ESP32 and SSOP5 footprints. Updated Partie_cmd.kicad_pcb, Partie_cmd.kicad_sch, and fp-lib-tabl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
    [Partie_cmd.kicad_pcb, Partie_cmd.kicad_sch]
2026-01-13 Ajout PCB audio
    [Audio.kicad_pcb, Audio.kicad_sch, Partie_audio.kicad_pcb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]
2026-01-13 fin schéma + Routage PCB cmd
    [Partie_cmd.kicad_pcb, Partie_cmd.kicad_sch, Partie_mécanique .kicad_sch]
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2026-01-20 MAJ PCB audio
    [Audio.kicad_pcb, Audio.kicad_sch]
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2026-01-20 Routage pcb cmd
    [Nomad.kicad_sch, Partie_cmd.kicad_pcb, Partie_cmd.kicad_sch]
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2026-01-24 Modification du schéma et du routage de la partie audio
    [Audio.kicad_pcb, Audio.kicad_sch]
2026-01-27 Fin routage pcb cmd
    :(
    [Partie_cmd.kicad_pcb, Partie_cmd.kicad_sch]
2026-01-27 fin routage pcb 1.1
    [Partie_cmd.kicad_pcb]
2026-01-27 Fin routage 1.2
    pour de vrai cette foix?
    [Partie_cmd.kicad_pcb, Partie_cmd.kicad_sch]
2026-01-27 replacement trous de perçage
    [Partie_cmd.kicad_pcb]
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2026-01-27 fin du routage
    svpsvpsvpsvpsvp
    [Partie_cmd.kicad_pcb, Partie_cmd.kicad_sch]
2026-01-27 Modification du PCB audio pour avoir un connecteur de 14 broches
    [Audio.kicad_pcb, Audio.kicad_sch]
2026-01-30 correction erreurs
    [Partie_cmd.kicad_pcb]
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2026-02-04 Document amplifier configuration challenges in README
    Added notes on amplifier issues with the old PCB and configuration attempts.
2026-02-07 Nettoyage des fichiers de la partie PCB
    [Audio.kicad_pcb, Audio.kicad_sch, ESP32-DEVKITC-32UE.step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]
2026-02-07 qques legeres modifs
    [Partie_cmd.kicad_pcb]
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2026-02-10 Création code controle moteurs
    [Audio.kicad_pcb]
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2026-02-14 Modification du PCB de la partie audio pour avoir une perle de ferrite avec une ampreinte plus grande
    [Audio.kicad_pcb, Audio.kicad_sch]
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2026-03-04 schema et pcb update
    [Partie_cmd.kicad_pcb, Partie_cmd.kicad_sch, freerouting.dsn]
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2026-03-13 New pcb avec des erreurs
    [Partie_cmd.kicad_pcb, Partie_cmd.kicad_sch, freerouting.dsn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]
2026-03-13 PCB final
    [Partie_cmd.kicad_pcb, freerouting.dsn, temp-freerouting.dsn]
2026-03-13 edit pcb
    [Partie_cmd.kicad_pcb, Partie_cmd.kicad_sch]
2026-03-14 edit 3v3 zone
    [Partie_cmd.kicad_pcb]
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2026-03-17 Last pcbss
    [Partie_cmd.kicad_pcb, Partie_cmd.kicad_sch]
2026-03-17 Finitions pcb
    [Partie_cmd.kicad_pcb]
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2026-04-07 Update README with Séance extra 21 notes
    Added notes from Séance extra 21 regarding PCB testing and audio issues.
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
